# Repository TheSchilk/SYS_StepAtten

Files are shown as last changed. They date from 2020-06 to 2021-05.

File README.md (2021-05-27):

# SYS StepAtten

### Philipp Schilk

A 127 Step Relay Step-Attenuator and 4-way input switcher designed to fit into a [Schiit SYS](https://www.schiit.com/products/sys) enclosure.

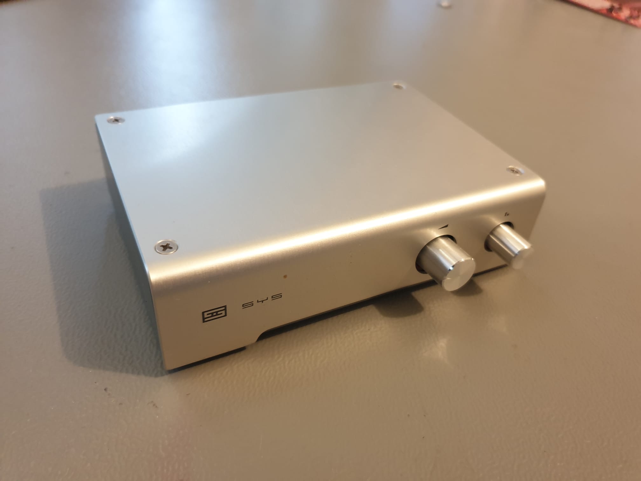
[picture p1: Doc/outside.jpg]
The finished unit.


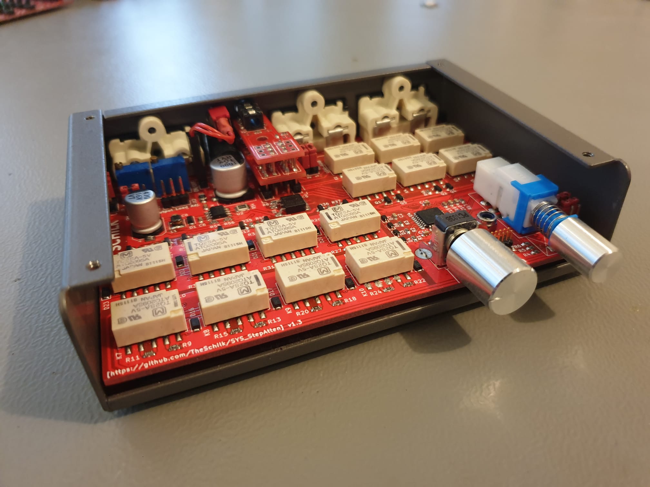
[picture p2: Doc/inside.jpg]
The inside.


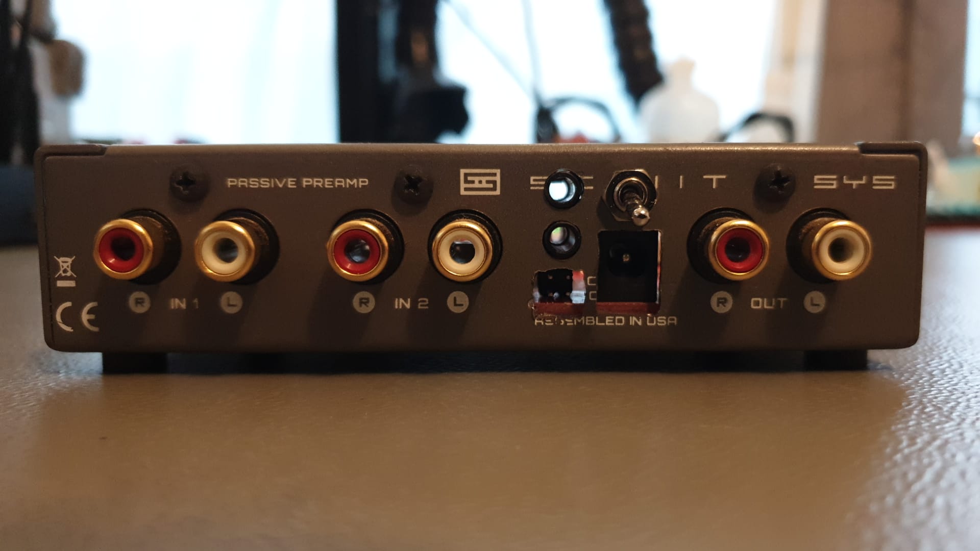
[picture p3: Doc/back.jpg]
The back.


## Specifications

| **Spec** | **Value** |
|---|---|
| Inputs | 2x Stereo 3.5mm, 2x Stereo RCA |
| Attenuator Type | Constant input impedance |
| Expected Input Impedance | 10K (can be adjusted) |
| Steps | 127 + Relay Mute |
| Power Input | 9Vdc, center positive barrel jack. 500mA+ |
| Power Consumption | Max 2.25W (250mA at 9VDc) |
| Control | Internal controls or wired remote control |

## Grounding
All inputs are fully isolated from each other.
RCA grounds can be kept seperate or joined. (Internal Jumper)
Audio ground can be kept seperate or joined to digital ground (Internal Jumper)

## Remote Control
Remote Control connector pinout (looking at connector from back of unit):

| 3V | GND  |
|---|---|
| **Sense** | **Poti** |

A remote consists of a potentiometer between 3V and GND with wiper connected to 'Poti'
A 10K resistor has to be placed between GND and Sense for the remote to be detected.
If the remote features a switch, it should short Sense to GND.

## Riser Board
Design files for the 3.5mm Connector Riser board [can be found here](https://github.com/TheSchilk/3.5mm_RiserPCB/releases/tag/v0.1).

## Switch Selection

The SYS is normally fitted with a toggle switch (ALPS SPUN191400), but
a momentary version of that switch also exists (ALPS SPUN190900).

The momentary switch is probably the better choice, but just in case
one wants to harvest as many parts as possible from an original SYS,
both are supported by the firmware.

The internal Jumper CFG1 is used to indicate which kind is installed.

| *Switch* | *CFG1 Setting* |
|:---:|:---:|
| Momentary (ALPS SPUN190900) | 0 |
| Toggle (ALPS SPUN191400)  | 1 |

Note that the unit has to be turned off and on again for this setting 
to take effect.

## Schematics, Gerbers, BOMs, ...
See [Github Releases](https://github.com/TheSchilk/SYS_StepAtten/releases).

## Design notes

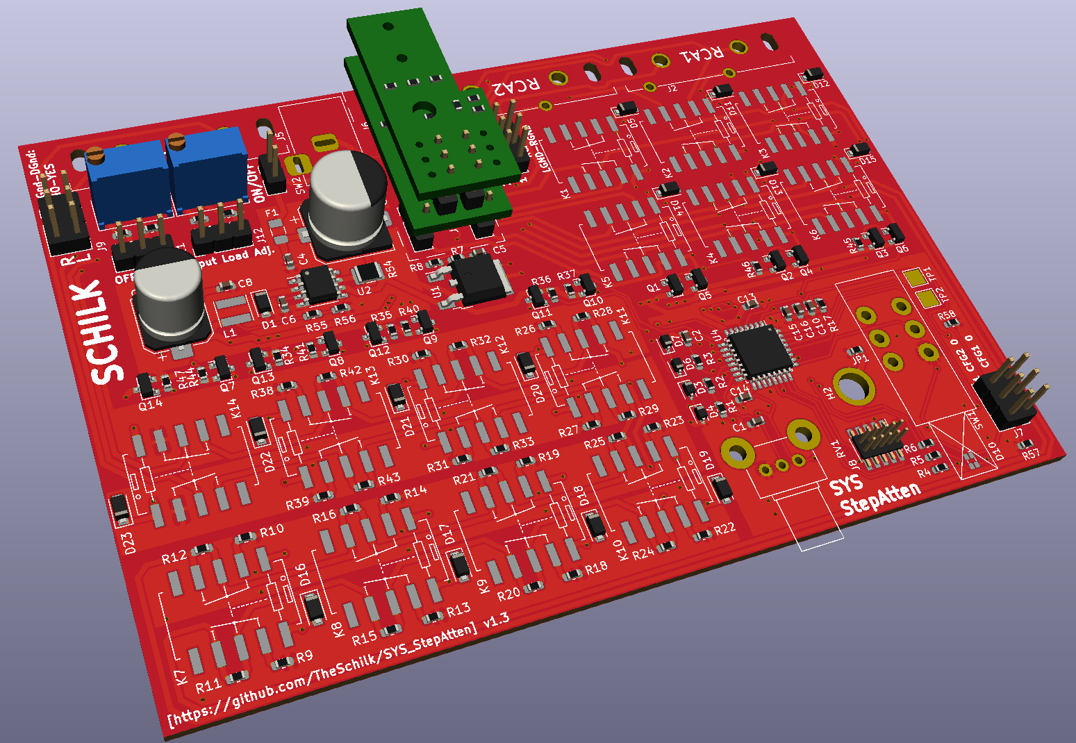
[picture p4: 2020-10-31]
Doc/pcb_render.png

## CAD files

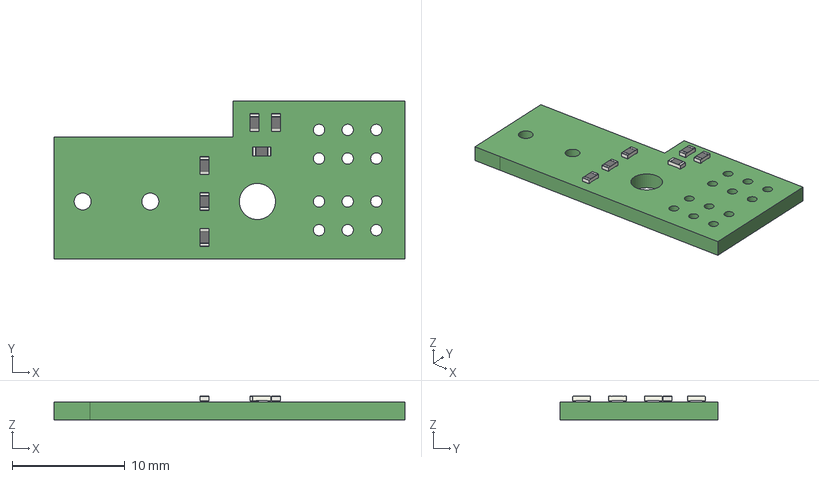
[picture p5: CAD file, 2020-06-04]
KiCad/SYS_StepAtten/RiserBoard_Top.step
31.1 x 14.0 x 2.10 mm

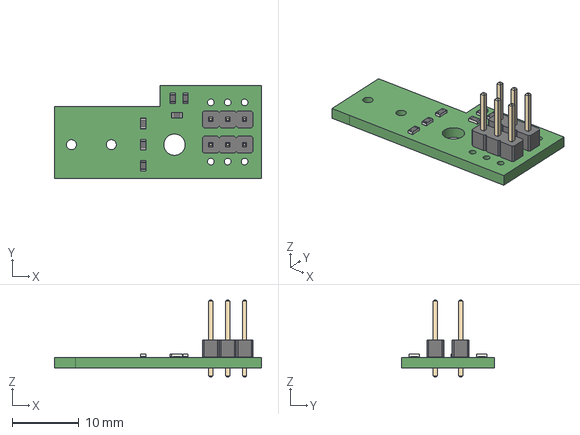
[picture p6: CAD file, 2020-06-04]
KiCad/SYS_StepAtten/RiserBoard_Mid.step
31.1 x 14.0 x 11.5 mm

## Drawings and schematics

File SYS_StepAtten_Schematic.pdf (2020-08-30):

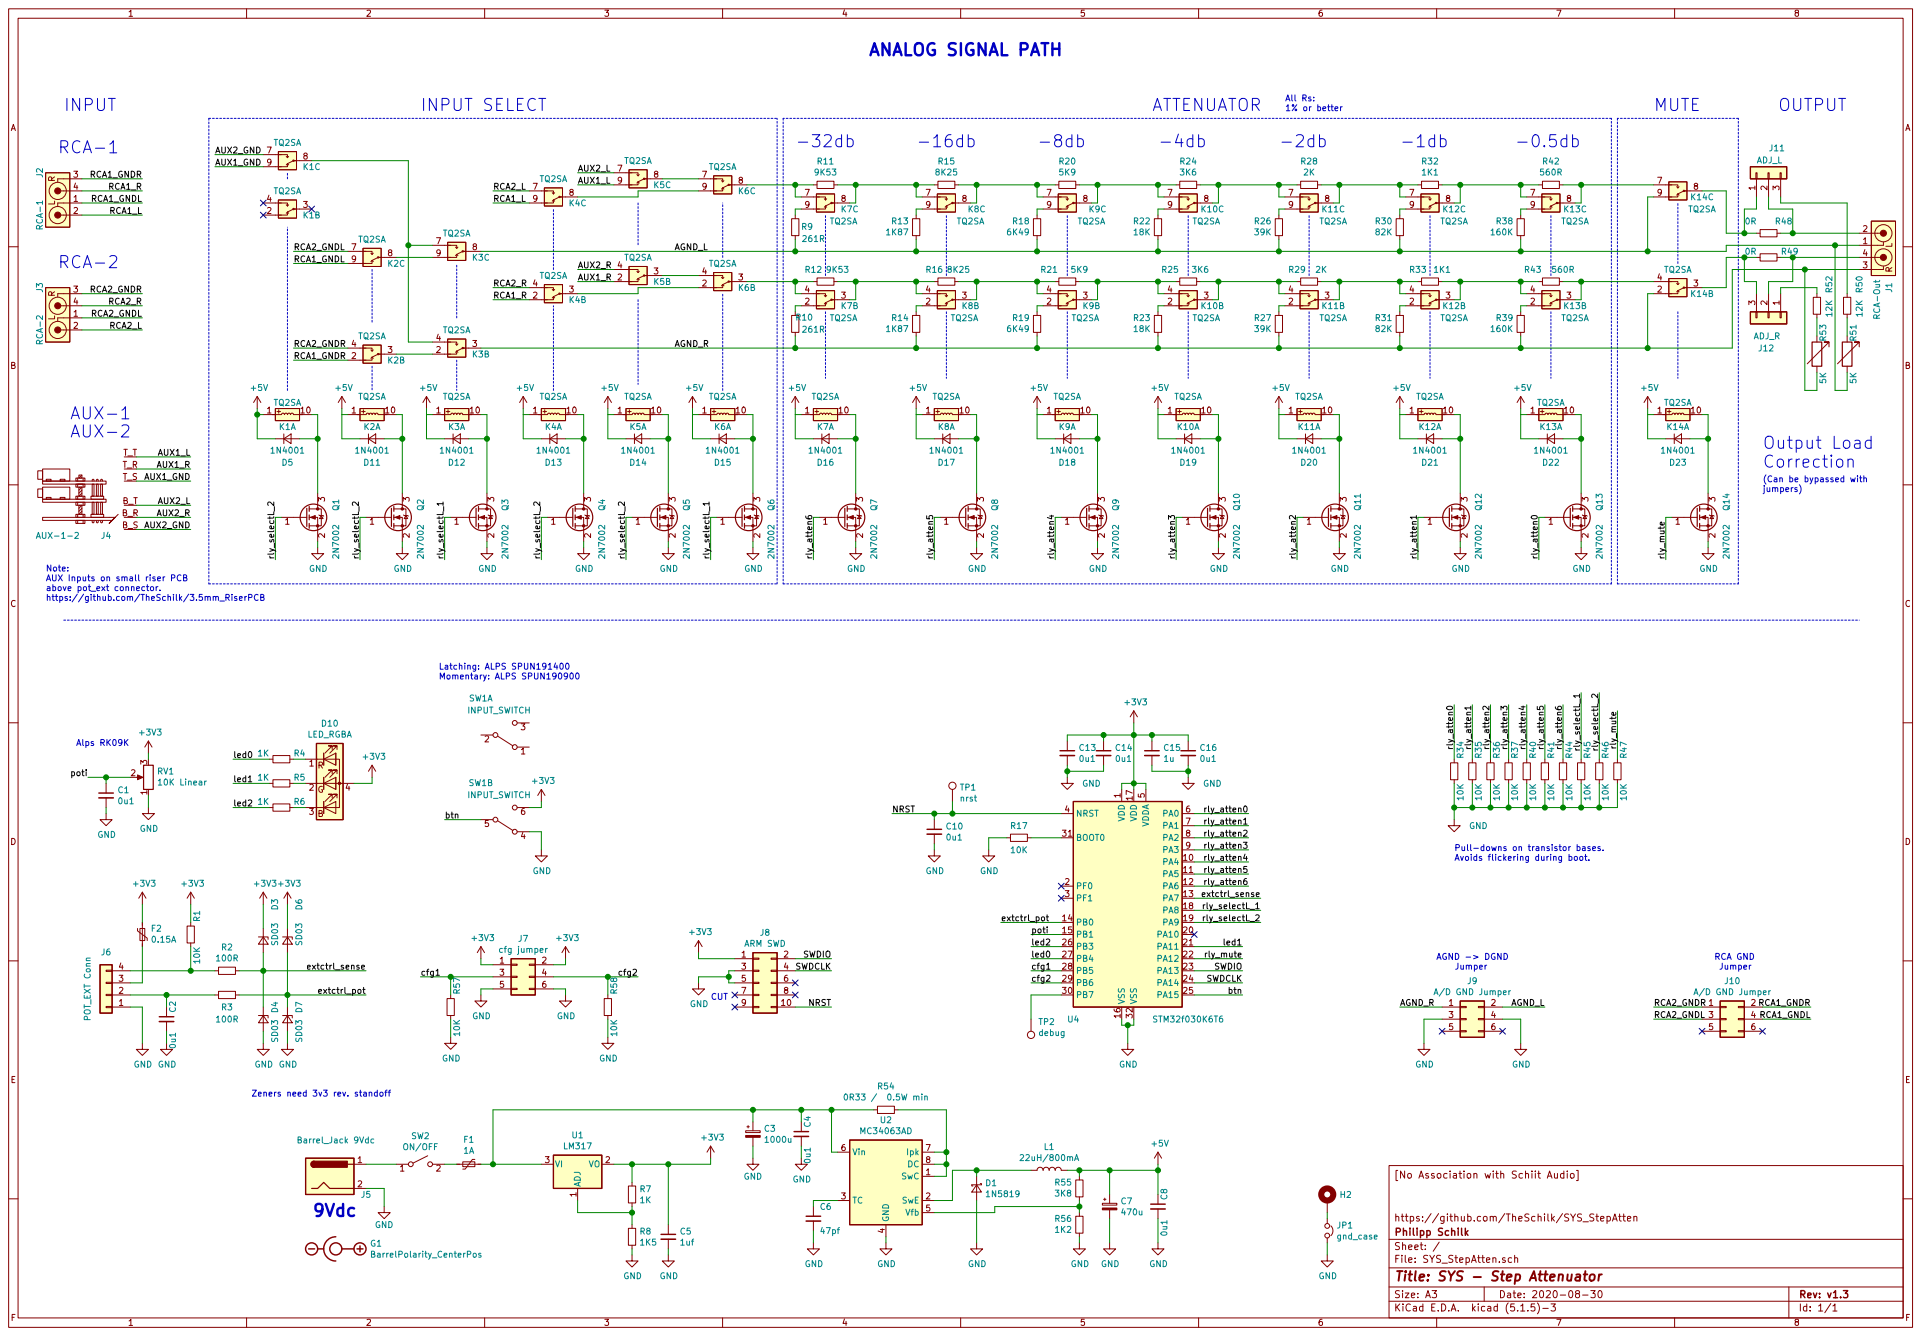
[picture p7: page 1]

All Rs: 1% or better

TQ2SA GND
Zeners need 3v3 rev. standoff AUX-2

(Can be bypassed with
jumpers)

Note: AUX Inputs on small riser PCB

1 PA4 10 PA5 11 PA6 12 PA7 13 PB0 14 PB1 15 VSS 16 VDD 17 PA8 18 PA9 19 PF0 2 PA10 20 PA11 21 PA12 22 PA13 23 PA14 24 PA15 25 PB3 26 PB4 27 PB5 28 PB6 29 PF1 3 PB7 30 BOOT0 31 VSS 32 NRST 4 VDDA

Pull-downs on transistor bases. Avoids flickering during boot. CUT

[No Association with Schiit Audio]
H2 GND

https://github.com/TheSchilk/SYS_StepAtten
File: SYS_StepAtten.sch Sheet: / Philipp Schilk

Id: 1/1 Title: SYS - Step Attenuator

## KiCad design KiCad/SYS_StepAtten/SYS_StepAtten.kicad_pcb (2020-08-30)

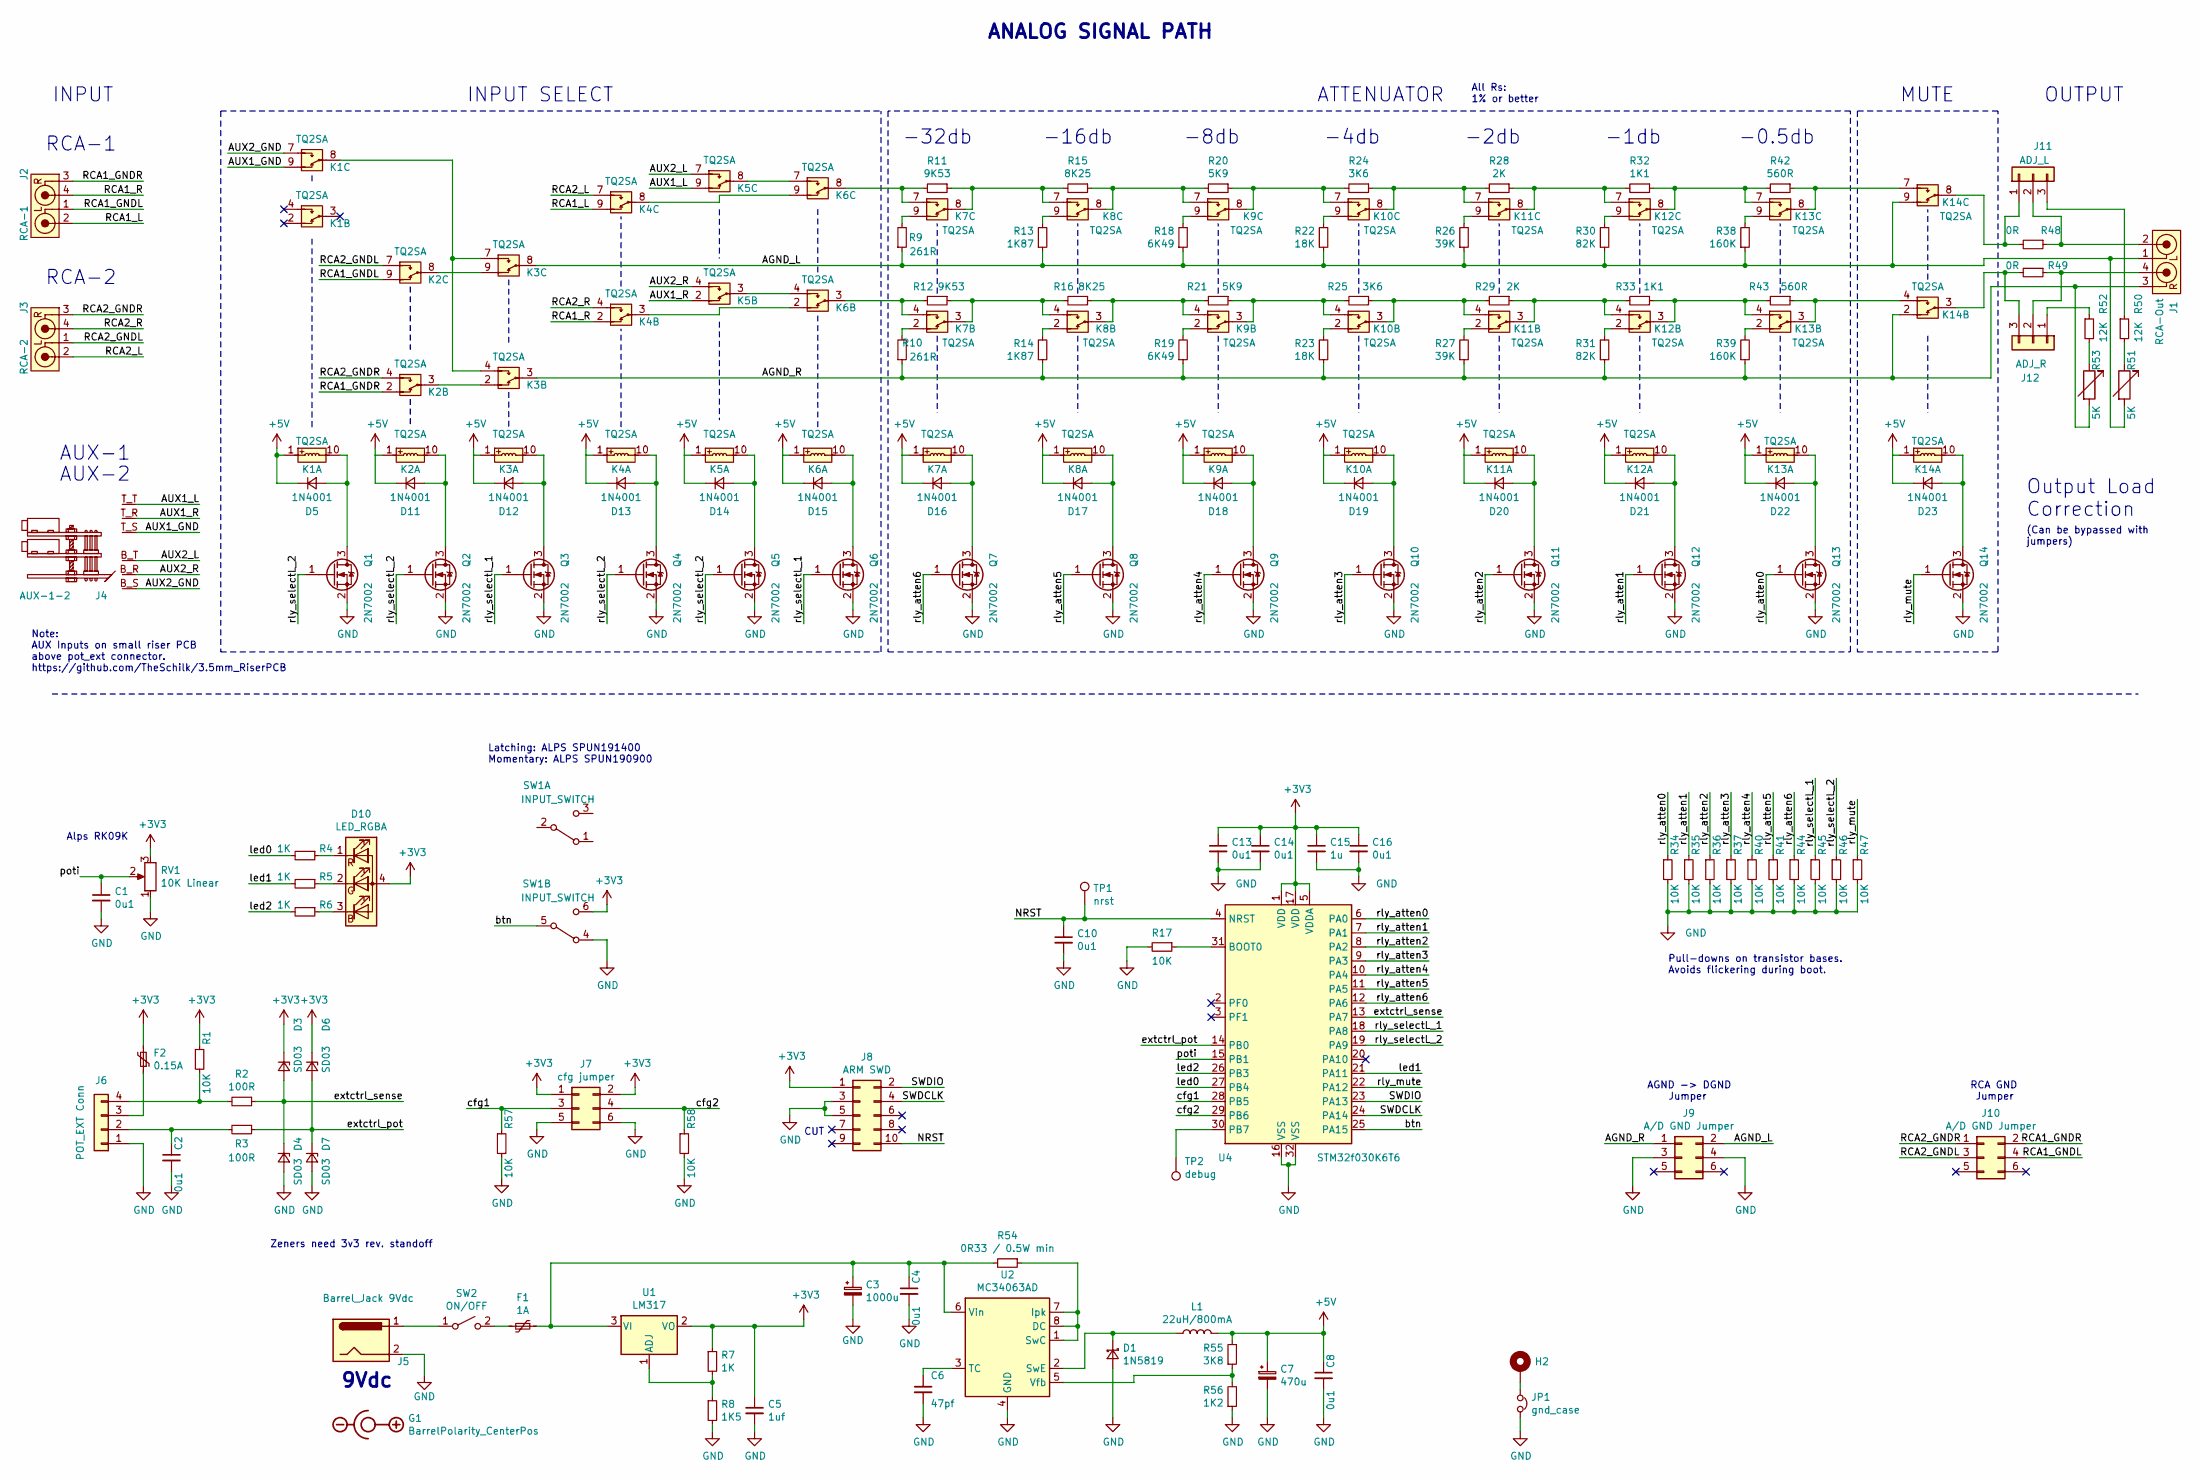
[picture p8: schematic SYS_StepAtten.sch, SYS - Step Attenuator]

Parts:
C1, C2, C4, C8, C10, C13, C14, C16: 0u1; C_0603_1608Metric
C3: 1000u; CP_Elec_10x10.5
C5: 1uf; C_0603_1608Metric
C6: 47pf; C_0603_1608Metric
C7: 470u; CP_Elec_8x10.5
C15: 1u; C_0603_1608Metric
D1: 1N5819; D_SOD-123F
D3, D4, D6, D7: SD03; D_SOD-323
D5, D11, D12, D13, D14, D15, D16, D17, D18, D19, D20, D21, D22, D23: 1N4001; D_SOD-123F
D10: LED_RGBA; RGB_LED_1.6x1.6x0.6
F1: 1A; Fuse_1206_3216Metric
F2: 0.15A; Fuse_1206_3216Metric
G1: BarrelPolarity_CenterPos; BarrelPolarity_3mm_CenterPos
H2: MH 1; MountingHole_4.3mm_M4_Pad_Via
J1: RCA-Out; RCA_KobiCon_161-4220-E
J2: RCA-1; RCA_KobiCon_161-4220-E
J3: RCA-2; RCA_KobiCon_161-4220-E
J4: AUX-1-2; 3.5mm_RiserPCB
J5: Barrel_Jack 9Vdc; BarrelJack_Horizontal
J6: POT_EXT Conn; PinHeader_2x02_P2.54mm_Horizontal
J7: cfg jumper; PinHeader_2x03_P2.54mm_Vertical
J8: ARM SWD; PinHeader_2x05_P1.27mm_Vertical_SMD
J9, J10: A/D GND Jumper; PinHeader_2x03_P2.54mm_Vertical
J11: ADJ_L; PinHeader_1x03_P2.54mm_Vertical
J12: ADJ_R; PinHeader_1x03_P2.54mm_Vertical
JP1: gnd_case; R_0603_1608Metric
K1, K2, K3, K4, K5, K6, K7, K8, K9, K10, K11, K12, K13, K14: TQ2SA; Panasonic_TQ2SA
L1: 22uH/800mA; L_Taiyo-Yuden_MD-4040
Q1, Q2, Q3, Q4, Q5, Q6, Q7, Q8, Q9, Q10, Q11, Q12, Q13, Q14: 2N7002; SOT-23
R1, R17, R34, R35, R36, R37, R40, R41, R44, R45, R46, R47, R57, R58: 10K; R_0603_1608Metric
R2, R3: 100R; R_0603_1608Metric
R4, R5, R6, R7: 1K; R_0603_1608Metric
R8: 1K5; R_0603_1608Metric
R9, R10: 261R; R_0603_1608Metric
R11, R12: 9K53; R_0603_1608Metric
R13, R14: 1K87; R_0603_1608Metric
R15, R16: 8K25; R_0603_1608Metric
R18, R19: 6K49; R_0603_1608Metric
R20, R21: 5K9; R_0603_1608Metric
R22, R23: 18K; R_0603_1608Metric
R24, R25: 3K6; R_0603_1608Metric
R26, R27: 39K; R_0603_1608Metric
R28, R29: 2K; R_0603_1608Metric
R30, R31: 82K; R_0603_1608Metric
R32, R33: 1K1; R_0603_1608Metric
R38, R39: 160K; R_0603_1608Metric
R42, R43: 560R; R_0603_1608Metric
R48, R49: 0R; R_0603_1608Metric
R50, R52: 12K; R_0603_1608Metric
R51, R53: 5K; Potentiometer_Bourns_3296W_Vertical
R54: 0R33 / 0.5W min; R_1210_3225Metric
R55: 3K8; R_0603_1608Metric
R56: 1K2; R_0603_1608Metric
RV1: 10K Linear; Potentiometer_Alps_RK09K_Single_Horizontal
SW1: INPUT_SWITCH; ALPS_SPUN191400
SW2: ON/OFF; PinHeader_1x02_P2.54mm_Vertical
TP1: nrst; TestPoint_Pad_2.5x2.5mm
TP2: debug; TestPoint_Pad_2.5x2.5mm
U1: LM317; TO-252-2
U2: MC34063AD; SOIC-8_3.9x4.9mm_P1.27mm
U4: STM32f030K6T6; LQFP-32_7x7mm_P0.8mm

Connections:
+3V3: C5.1, C13.1, C14.1, C15.1, C16.1, D3.1 (K), D6.1 (K), D10.4 (A), F2.2, J7.1, J7.2, J8.1, R1.1, R7.1, RV1.3, SW1.6 (C), U1.2 (VO), U4.1 (VDD), U4.5 (VDDA), U4.17 (VDD)
+5V: C7.1, C8.1, D5.1 (K), D11.1 (K), D12.1 (K), D13.1 (K), D14.1 (K), D15.1 (K), D16.1 (K), D17.1 (K), D18.1 (K), D19.1 (K), D20.1 (K), D21.1 (K), D22.1 (K), D23.1 (K), K1.1, K2.1, K3.1, K4.1, K5.1, K6.1, K7.1, K8.1, K9.1, K10.1, K11.1, K12.1, K13.1, K14.1, L1.2, R55.2
/AGND_L: J1.1, J9.2, K3.8, K14.9, R9.1, R13.1, R18.1, R22.1, R26.1, R30.1, R38.1, R51.2
/AGND_R: J1.3, J9.1, K3.3, K14.2, R10.1, R14.1, R19.1, R23.1, R27.1, R31.1, R39.1, R53.2
/AUX1_GND: J4.T_S, K1.9
/AUX1_L: J4.T_T, K5.9
/AUX1_R: J4.T_R, K5.2
/AUX2_GND: J4.B_S, K1.7
/AUX2_L: J4.B_T, K5.7
/AUX2_R: J4.B_R, K5.4
/NRST: C10.1, J8.10, TP1.1, U4.4 (NRST)
/RCA1_GNDL: J2.1, J10.4, K2.9
/RCA1_GNDR: J2.3, J10.2, K2.2
/RCA1_L: J2.2, K4.9
/RCA1_R: J2.4, K4.2
/RCA2_GNDL: J3.1, J10.3, K2.7
/RCA2_GNDR: J3.3, J10.1, K2.4
/RCA2_L: J3.2, K4.7
/RCA2_R: J3.4, K4.4
/SWDCLK: J8.4, U4.24 (PA14)
/SWDIO: J8.2, U4.23 (PA13)
/btn: SW1.5 (B), U4.25 (PA15)
/cfg1: J7.3, R57.1, U4.28 (PB5)
/cfg2: J7.4, R58.1, U4.29 (PB6)
/extctrl_pot: D6.2 (A), D7.1 (K), R3.1, U4.14 (PB0)
/extctrl_sense: D3.2 (A), D4.1 (K), R2.1, U4.13 (PA7)
/led0: R4.2, U4.27 (PB4)
/led1: R5.2, U4.21 (PA11)
/led2: R6.2, U4.26 (PB3)
/poti: C1.1, RV1.2, U4.15 (PB1)
/rly_atten0: Q13.1 (G), R34.1, U4.6 (PA0)
/rly_atten1: Q12.1 (G), R35.1, U4.7 (PA1)
/rly_atten2: Q11.1 (G), R36.1, U4.8 (PA2)
/rly_atten3: Q10.1 (G), R37.1, U4.9 (PA3)
/rly_atten4: Q9.1 (G), R40.1, U4.10 (PA4)
/rly_atten5: Q8.1 (G), R41.1, U4.11 (PA5)
/rly_atten6: Q7.1 (G), R44.1, U4.12 (PA6)
/rly_mute: Q14.1 (G), R47.1, U4.22 (PA12)
/rly_selectL_1: Q3.1 (G), Q6.1 (G), R45.1, U4.18 (PA8)
/rly_selectL_2: Q1.1 (G), Q2.1 (G), Q4.1 (G), Q5.1 (G), R46.1, U4.19 (PA9)
GND: C1.2, C2.2, C3.2, C4.2, C5.2, C6.2, C7.2, C8.2, C10.2, C13.2, C14.2, C15.2, C16.2, D1.2 (A), D4.2 (A), D7.2 (A), J5.2, J6.1, J7.5, J7.6, J8.3, J8.5, J9.3, J9.4, JP1.2, Q1.2 (S), Q2.2 (S), Q3.2 (S), Q4.2 (S), Q5.2 (S), Q6.2 (S), Q7.2 (S), Q8.2 (S), Q9.2 (S), Q10.2 (S), Q11.2 (S), Q12.2 (S), Q13.2 (S), Q14.2 (S), R8.2, R17.2, R34.2, R35.2, R36.2, R37.2, R40.2, R41.2, R44.2, R45.2, R46.2, R47.2, R56.1, R57.2, R58.2, RV1.1, SW1.4 (A), U2.4 (GND), U4.16 (VSS), U4.32 (VSS)
unnamed: C2.1, J6.2, R3.2
unnamed: C3.1, C4.1, F1.1, R54.2, U1.3 (VI), U2.6 (Vin)
unnamed: C6.1, U2.3 (TC)
unnamed: D1.1 (K), L1.1, U2.2 (SwE)
unnamed: D5.2 (A), K1.10, Q1.3 (D)
unnamed: D10.1 (RK), R4.1
unnamed: D10.2 (GK), R5.1
unnamed: D10.3 (BK), R6.1
unnamed: D11.2 (A), K2.10, Q2.3 (D)
unnamed: D12.2 (A), K3.10, Q3.3 (D)
unnamed: D13.2 (A), K4.10, Q4.3 (D)
unnamed: D14.2 (A), K5.10, Q5.3 (D)
unnamed: D15.2 (A), K6.10, Q6.3 (D)
unnamed: D16.2 (A), K7.10, Q7.3 (D)
unnamed: D17.2 (A), K8.10, Q8.3 (D)
unnamed: D18.2 (A), K9.10, Q9.3 (D)
unnamed: D19.2 (A), K10.10, Q10.3 (D)
unnamed: D20.2 (A), K11.10, Q11.3 (D)
unnamed: D21.2 (A), K12.10, Q12.3 (D)
unnamed: D22.2 (A), K13.10, Q13.3 (D)
unnamed: D23.2 (A), K14.10, Q14.3 (D)
unnamed: F1.2, SW2.2 (B)
unnamed: F2.1, J6.3
unnamed: H2.1, JP1.1
unnamed: J1.2, J11.2, R48.1
unnamed: J1.4, J12.2, R49.1
unnamed: J5.1, SW2.1 (A)
unnamed: J6.4, R1.2, R2.2
unnamed: J11.1, K14.8, R48.2
unnamed: J11.3, R50.1
unnamed: J12.1, R52.1
unnamed: J12.3, K14.3, R49.2
unnamed: K1.8, K3.4, K3.7
unnamed: K2.3, K3.2
unnamed: K2.8, K3.9
unnamed: K4.3, K6.2
unnamed: K4.8, K6.9
unnamed: K5.3, K6.4
unnamed: K5.8, K6.7
unnamed: K6.3, K7.4, R12.2
unnamed: K6.8, K7.7, R11.2
unnamed: K7.2, R10.2
unnamed: K7.3, K8.4, R12.1, R16.2
unnamed: K7.8, K8.7, R11.1, R15.2
unnamed: K7.9, R9.2
unnamed: K8.2, R14.2
unnamed: K8.3, K9.4, R16.1, R21.2
unnamed: K8.8, K9.7, R15.1, R20.2
unnamed: K8.9, R13.2
unnamed: K9.2, R19.2
unnamed: K9.9, R18.2
unnamed: K10.2, R23.2
unnamed: K10.3, K11.4, R25.1, R29.2
unnamed: K9.3, K10.4, R21.1, R25.2
unnamed: K9.8, K10.7, R20.1, R24.2
unnamed: K10.8, K11.7, R24.1, R28.2
unnamed: K10.9, R22.2
unnamed: K11.2, R27.2
unnamed: K11.3, K12.4, R29.1, R33.2
unnamed: K11.8, K12.7, R28.1, R32.2
unnamed: K11.9, R26.2
unnamed: K12.2, R31.2
unnamed: K12.3, K13.4, R33.1, R43.2
unnamed: K12.8, K13.7, R32.1, R42.2
unnamed: K12.9, R30.2
unnamed: K13.2, R39.2
unnamed: K13.3, K14.4, R43.1
unnamed: K13.8, K14.7, R42.1
unnamed: K13.9, R38.2
unnamed: R7.2, R8.1, U1.1 (ADJ)
unnamed: R17.1, U4.31 (BOOT0)
unnamed: R50.2, R51.1
unnamed: R52.2, R53.1
unnamed: R54.1, U2.1 (SwC), U2.7 (Ipk), U2.8 (DC)
unnamed: R55.1, R56.2, U2.5 (Vfb)
unnamed: TP2.1, U4.30 (PB7)

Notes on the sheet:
ATTENUATOR
INPUT SELECT
ANALOG SIGNAL PATH
OUTPUT
INPUT
CUT
MUTE
AUX-2
AUX-1
RCA-2
RCA-1
-0.5db
-1db
-2db
-4db
-8db
-16db
-32db
Output Load Correction
All Rs: 1% or better
9Vdc
Note: AUX Inputs on small riser PCB above pot_ext connector. https://github.com/TheSchilk/3.5mm_RiserPCB
AGND -> DGND Jumper
RCA GND Jumper
Zeners need 3v3 rev. standoff
Pull-downs on transistor bases. Avoids flickering during boot.
Latching: ALPS SPUN191400 Momentary: ALPS SPUN190900
Alps RK09K
(Can be bypassed with jumpers)

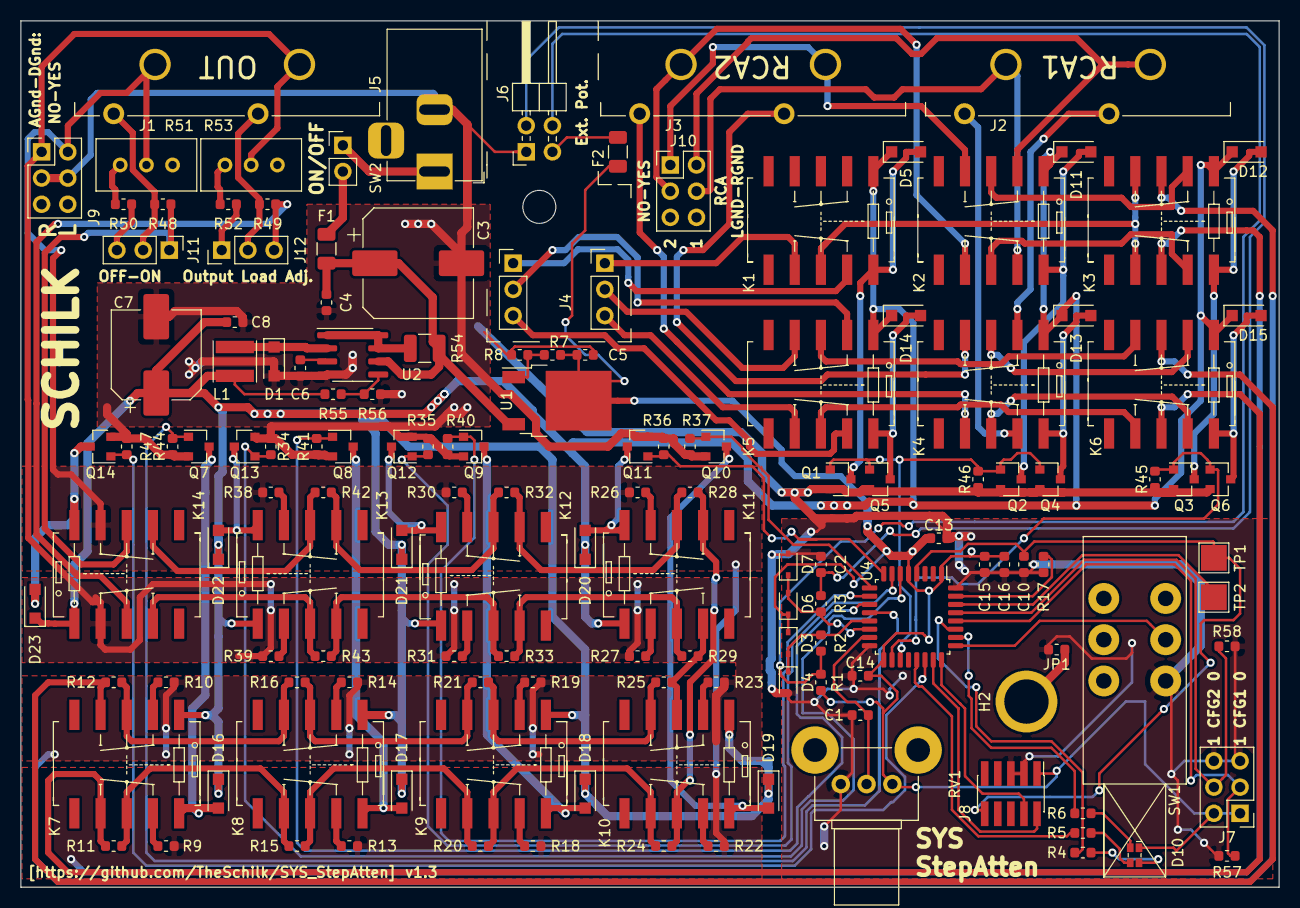
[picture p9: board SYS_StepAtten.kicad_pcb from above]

Board: 2 copper layers, 122.0 x 84.0 mm, 145 parts (1 on the bottom side), 117 nets.

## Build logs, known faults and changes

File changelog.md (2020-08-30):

# v1.3
 - Fixed pinout problem
 - Added short protection to external control connector

# v1.2
 - Added pulldowns on config jumpers.

# v1.1
 - Moved to DC input
 - Change to switchmode power supply
 - Updated external interface to support switch
 - Added jumper for load adjustment

# v1.0
 - Should now actually fit Schiit Sys
 - Added grounding configuration jumpers
 - Added series load-adjustment
 - Updated to v0.1 of 3.5mm riser board
 - Changed to an RGB led
 - Fixed pinouts of connectors
 - Added ESD protection to external pot interface
 - Added pulldowns to transistor bases
 - Changed mute to be short

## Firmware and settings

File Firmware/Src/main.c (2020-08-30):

/*
 * Firmware for SYS-StepAtten
 * https://www.github.com/TheSchilk/SYS_StepAtten
 *
 *  Created on: 23 Apr 2020
 *      Author: pschilk
 */
#include <sys_stepatten.h>

int main(void)
{
	// Configure 1ms SysTick Interrupt
	systick_init();

	// Configure all GPIOs
  	gpio_init();

  	// Configure ADC
	adc_init();

	// Setup UI
	ui_setup();

	while(1){
		ui_update();
		flash_attempt_write();
		systick_dlyms(100);
	}
}

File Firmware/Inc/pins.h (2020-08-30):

/*
 * pins.h
 *
 *  Created on: 23 Apr 2020
 *      Author: pschilk
 */

#ifndef PINS_H_
#define PINS_H_

#include <stm32f0xx.h>

/*
 * Definitions of all Pin Assignments
 * !! Any section marked with '*' is not solely dependent on definitions in this file
 */

// Internal Poti Input *
#define PIN_POT               GPIO_Pin_1
#define PORT_POT              GPIOB
#define AN_CH_POT             ADC_Channel_9

// Input Select Button
#define PIN_SW                GPIO_Pin_15
#define PORT_SW               GPIOA

// External Poti Input *
#define PIN_POT_EXT           GPIO_Pin_0
#define PORT_POT_EXT          GPIOB
#define AN_CH_POT_EXT         ADC_Channel_8

// External Poti Connected Sense *
#define PIN_SENSE_EXT         GPIO_Pin_7
#define PORT_SENSE_EXT        GPIOA
#define AN_CH_SENSE_EXT       ADC_Channel_7

// LED 0
#define PIN_LED_0             GPIO_Pin_4
#define PORT_LED_0            GPIOB

// LED 1
#define PIN_LED_1             GPIO_Pin_11
#define PORT_LED_1            GPIOA

// LED 2
#define PIN_LED_2             GPIO_Pin_3
#define PORT_LED_2            GPIOB

// Attenuator Relay Output *
#define PINS_RLY_ATTEN        (GPIO_Pin_0|GPIO_Pin_1|GPIO_Pin_2|GPIO_Pin_3|GPIO_Pin_4|GPIO_Pin_5|GPIO_Pin_6)
#define PINS_RLY_ATTEN_MASK   0x7F
#define PINS_RLY_ATTEN_SHIFT  0
#define PORT_RLY_ATTEN        GPIOA

// Mute Relay Output
#define PIN_RLY_MUTE          GPIO_Pin_12
#define PORT_RLY_MUTE         GPIOA

// Input Select Relay Output 1
#define PIN_RLY_SEL1          GPIO_Pin_8
#define PORT_RLY_SEL1         GPIOA

// Input Select Relay Output 2
#define PIN_RLY_SEL2          GPIO_Pin_9
#define PORT_RLY_SEL2         GPIOA

// Configuration Jumper 1
#define PIN_CFG_1             GPIO_Pin_5
#define PORT_CFG_1            GPIOB

// Configuration Jumper 2
#define PIN_CFG_2             GPIO_Pin_6
#define PORT_CFG_2            GPIOB

// Debug Test Point
#define PIN_DBG               GPIO_Pin_7
#define PORT_DBG              GPIOB

#endif /* PINS_H_ */

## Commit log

2020-03-10 Setup KiCad Project, added Relay Symbol
    [SYS_StepAtten.kicad_pcb, SYS_StepAtten.sch]
2020-03-15 Added Multi-Device Symbol
2020-03-16 Added Draft of Analog Signal Path
    [SYS_StepAtten.sch]
2020-03-21 Signal path layout done, no resistor values yet
    sync
    Analog path layout done, no resistor vals yet
    [SYS_StepAtten.sch]
2020-04-07 Schematic first draft
    Finished Schematic
    [RiserBoard_Mid.step, RiserBoard_Top.step, SYS_StepAtten.kicad_pcb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]
2020-04-07 fixed labels
    [SYS_StepAtten.sch]
2020-04-07 Updated Riser board footprint
2020-04-07 Schematic Refinments, Changed Relays and moved to own power rail
    [SYS_StepAtten.kicad_pcb, SYS_StepAtten.sch]
2020-04-08 Basic Sorting Done
    [SYS_StepAtten.kicad_pcb, SYS_StepAtten.sch]
2020-04-08 Setup netclasses
    [SYS_StepAtten.kicad_pcb]
2020-04-08 finished testing board v0.0
    [SYS_StepAtten.kicad_pcb, SYS_StepAtten.sch]
2020-04-08 pulled in fixed footprint for alps switch
2020-04-08 moved silkscreen lbl
    [SYS_StepAtten.kicad_pcb]
2020-04-08 Added page info, exported gerber+schm. ready for production
    [SYS_StepAtten-B_Cu.gbr, SYS_StepAtten-B_Mask.gbr, SYS_StepAtten-B_Paste.gbr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]
2020-04-23 Added Debug Pin to CubeMX Setup
2020-05-04 Pulled in new Switch footprint
2020-05-17 Deleted Old PCB, will have to redo
    [SYS_StepAtten.kicad_pcb]
2020-05-17 Fixed Output RCA Jack connection
    [SYS_StepAtten.sch]
2020-05-17 Cleared Annotations, Will have to redo pcb anyway
    [SYS_StepAtten.sch]
2020-05-23 Added Series Output Load Adjustment
    [SYS_StepAtten.sch]
2020-05-23 Reassigned Selection Relays
    [SYS_StepAtten.sch]
2020-05-23 Changed Mute to be short
    [SYS_StepAtten.sch]
2020-05-23 Added Pulldowns on transitors
    [SYS_StepAtten.sch]
2020-05-23 Added Ground Config Jumpers
    [SYS_StepAtten.sch]
2020-05-23 Changed Mounting Hole Grounding
    [SYS_StepAtten.sch]
2020-05-24 Updated Power Supply
    [SYS_StepAtten.sch]
2020-05-24 Pulled in v0.1 3.5mm Riser PCB
    [RiserBoard_Mid.step, RiserBoard_Top.step]
2020-05-24 Changed to RGB LED
    [SYS_StepAtten.sch]
2020-05-24 Pulled in new RCA_Stereo Symbol, Made sure L/R Channels are correct
    [SYS_StepAtten.sch]
2020-05-24 Added ESD protection to external poti interface
    [SYS_StepAtten.sch]
2020-05-24 Added Mounting Hole Footprint
    [SYS_StepAtten.sch]
2020-05-24 Annotated Schematic, Added last few footprints
    [SYS_StepAtten.sch]
2020-05-24 SYS Base Layout
    [SYS_StepAtten.kicad_pcb]
2020-05-24 Pulled in 3.5mm Riser again to fix problem with hole spacing...
    [RiserBoard_Mid.step, RiserBoard_Top.step, SYS_StepAtten.kicad_pcb]
2020-05-25 Base without relays
    [SYS_StepAtten.kicad_pcb, SYS_StepAtten.sch]
2020-05-25 No 2nd Mounting Hole
    [SYS_StepAtten.kicad_pcb]
2020-05-25 1st Draft Parts Placement
    [SYS_StepAtten.kicad_pcb]
2020-05-27 First Routing Draft
    [SYS_StepAtten.kicad_pcb, SYS_StepAtten.sch]
2020-06-04 Generated production files for v1.0
    [SYS_StepAtten-B_Cu.gbr, SYS_StepAtten-B_Mask.gbr, SYS_StepAtten-B_Paste.gbr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]
2020-06-04 Small Fixes. Pfuh.
    [SYS_StepAtten.kicad_pcb]
2020-06-04 Regenerated Production Files
    [SYS_StepAtten-B_Cu.gbr, SYS_StepAtten-B_Mask.gbr, SYS_StepAtten-B_SilkS.gbr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]
2020-07-09 Empty STM32CubeIDE Project
2020-07-09 Added ARM/ST CMSIS Version 1.5.0 (STSW-STM32048)
2020-07-09 Added ST STDPeriphLib Version 1.5.0 (STSW-STM32048)
2020-07-09 Simple Test ADC-> Atten
2020-07-12 Updated Schematic
    - Changed to DC Input
    - Changed to Switchmode powersupply
    - Updated external interface to support button
    - Added jumper for load-adjustement
    [SYS_StepAtten.sch]
2020-07-12 Layout updated
    [SYS_StepAtten.kicad_pcb]
2020-07-12 Updated PCB
    [SYS_StepAtten.kicad_pcb]
2020-07-12 Generated Production Files
    [SYS_StepAtten-B_Cu.gbr, SYS_StepAtten-B_Mask.gbr, SYS_StepAtten-B_Paste.gbr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]
2020-08-28 PCB v1.1 ready.
2020-08-28 Added Power Specs.
2020-08-29 Added Pulldowns to configuration jumpers
    [SYS_StepAtten-B_Cu.gbr, SYS_StepAtten-B_Mask.gbr, SYS_StepAtten-B_Paste.gbr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]
2020-08-29 Generated production files.
    [SYS_StepAtten-B_Cu.gbr, SYS_StepAtten-B_Mask.gbr, SYS_StepAtten-B_Paste.gbr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]
2020-08-30 Disable interrupts during Flash operations
2020-08-30 Groundwork for external control
2020-08-30 Fixed pinout
    [SYS_StepAtten.sch]
2020-08-30 Mute on powerup.
2020-08-30 Added ADC scaling to utilise whole atten range
2020-08-30 Added fuse to ext. ctrl. connection
    [SYS_StepAtten.sch]
2020-08-30 Updated Layout.
    [SYS_StepAtten.kicad_pcb]
2020-08-30 Generated v1.3 Production Files
    [SYS_StepAtten-B_Cu.gbr, SYS_StepAtten-B_Mask.gbr, SYS_StepAtten-B_Paste.gbr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]
2020-08-30 Updated changelod.md for pcb_v1.3
2020-09-27 Flash LED on when input is saved.
2020-10-31 Hide BOM from language Github's Language Stats
